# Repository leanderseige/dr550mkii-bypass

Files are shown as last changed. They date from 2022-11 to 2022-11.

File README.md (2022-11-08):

# Fixing Dr.Rhythm DR-550 MKII 

This is the documentation of how I fixed my DR-550 MKII. This is not a tutorial and this is not a recommendation. **WARNING! Trying to fix your machine this way may lead to irreparable and ultimate damage. It definetly would modify it irreversible. Please note that opening and modifying your device is on YOUR OWN RISK AND RESPONSIBILITY.**  And by the way, your machine may have another defect than mine.

I have one of those broken BOSS DR-550 MKII with extremely low and noisy signal on the outputs. And I couldn't find any documentation on how to fix it. But it was a huge help to find the "service notes" manual online, including the circuit diagram of the entire machine here: https://www.synthxl.com/boss-dr-550-mkii/ (PDF: https://www.synthxl.com/wp-content/uploads/2020/03/Boss-DR-550-MKII-Service-Notes.pdf)

I could hear the signal very low on the left headphone which gave me hope that the entire digital part of the machine would be ok and that just the analog output amplifiers would be the problem. I was not able to find any visual indications of faulty components. Capacitors and everything else looked good. So the next idea was to find the output pins of the digital-analog converter (DAC) to see if there was actually a proper analog signal produced.

With the help of the service manual I was able to identify IC103 as the DAC chip and PINs 6 and 11 to be the primary analog output pins. So I built the following simple stereo amplifier in order to connect the machine to other audio devices, in my case my audio mixer. This solution is not really a fix, it is a bypass, so to say.

Warning! Your device may suffer from a different problem and imitating the following steps might not solve your problem. Opening and/or modifying your device is on your own risk and it is very likely that you will loose any warranty. Some of the following steps modify the device irreversibly. This is a documentation of what I did. This is not a tutorial, not even a recommendation.

## Amplifier

I decided to use a very simple one-transistor amplifier just to see if my plan would work at all. I experimented with different values for the components and this was the first attempt delivering a usable signal to my audio mixer. I am sure this can be done better. Feel free to make suggestions for a better amp. The stereo panorama seemed not to be right in the middle, maybe I should have searched components for both channels which match each other as good as possible. I intend using the left (mono) channel in most cases anyway so this is no big thing at all. Turning the pan knob a little doesn't hurt either.

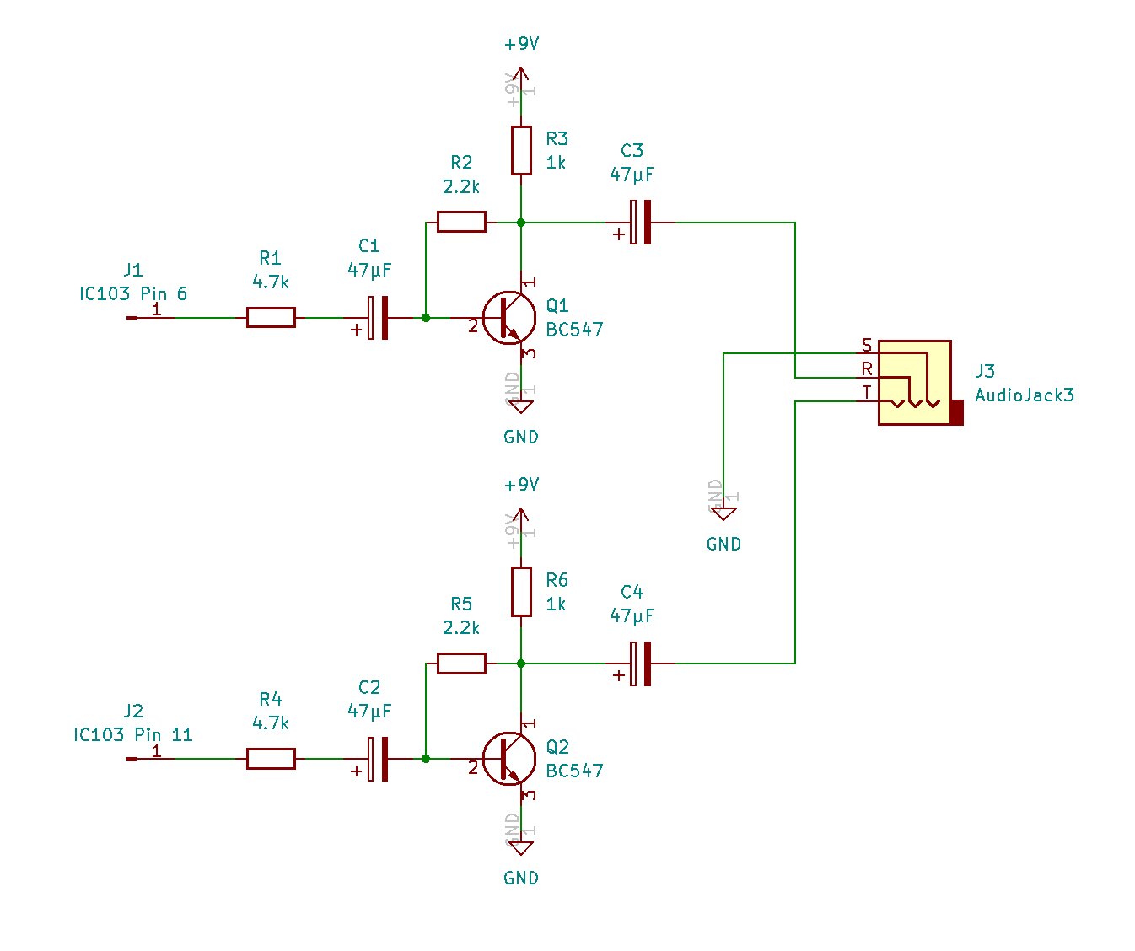
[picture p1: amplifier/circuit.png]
Stereo Amplifier


## Modifications

I attached the amplifier to Pins 11 and 6 of the DAC IC103 which provide the left (11) and right (6) analog audio channels.

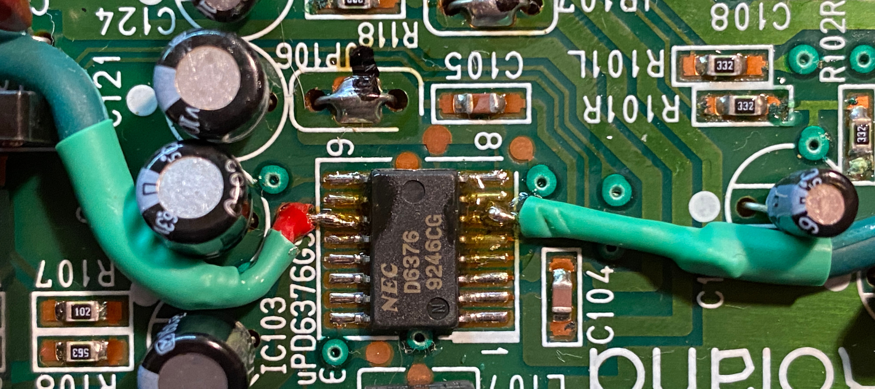
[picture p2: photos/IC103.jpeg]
ataching to DAC


Analyzing the original circuit diagram of the DR-550MKII -- I identified the capacitor C101 as the perfect spot to attach wires for stealing +9V in order to power the amplifier. 

(Left: top side, Right: bottom side with wires attached)

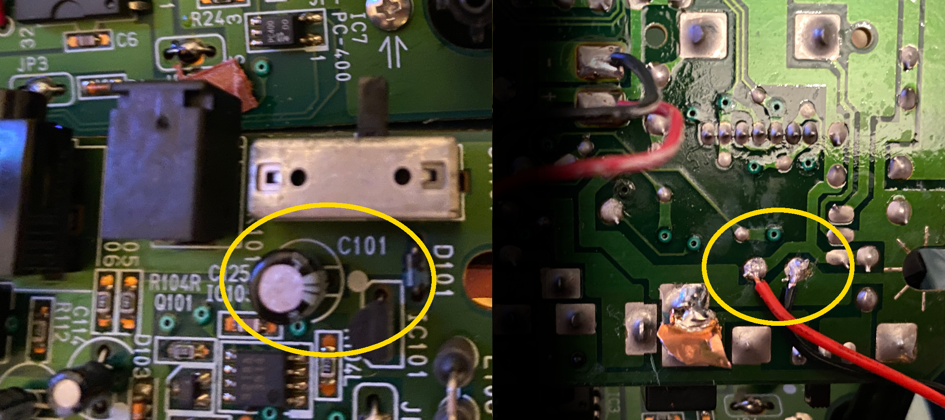
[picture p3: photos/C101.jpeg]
powering the DAC


## Damaging

In order to get the output out of the case I cut the axis of the original volume potentiometer. I also cut open the foil several times.

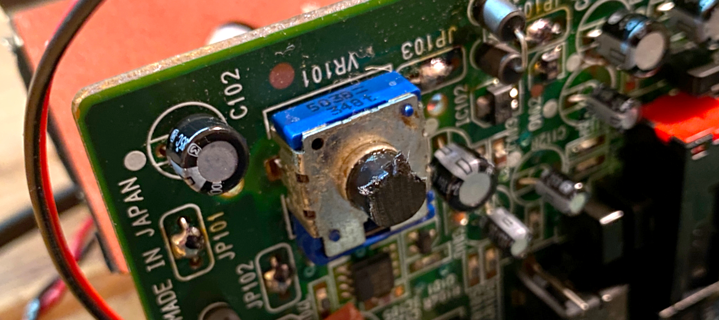
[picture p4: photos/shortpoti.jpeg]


## Putting it all together

Eventually I removed the battery compartment completely in order to use the space for the amplifier. Attention: the outer layer of the foil conducts electricity! I had to isolate the amplifier using bubble wrap.

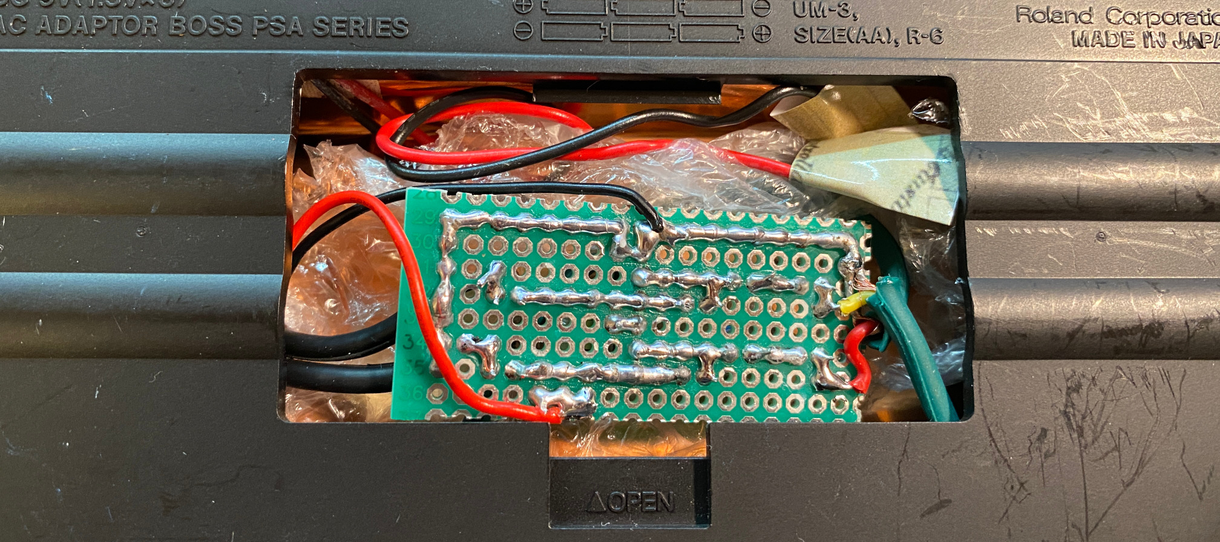
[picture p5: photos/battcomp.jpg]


I also removed the now uselss volume knob. Instead I designed a case for a 3.5mm jack fitting perfectly where the former volume knob was.

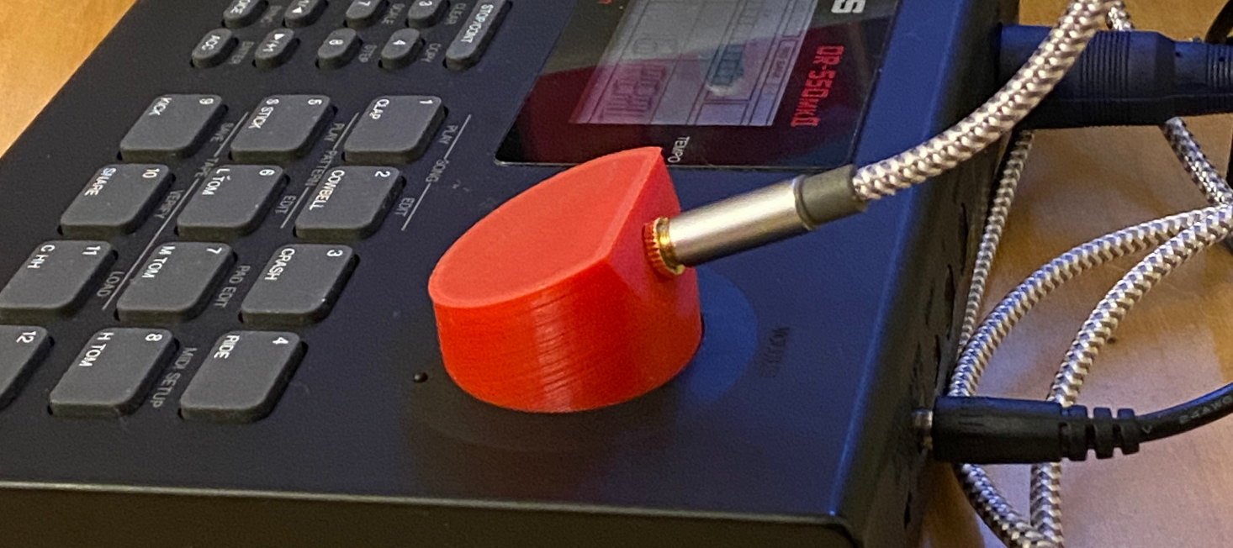
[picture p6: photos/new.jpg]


The 3D model is pre-rotated for optimal printing.

**WARNING!** Any of the above steps can ruin your device! Opening or modifying your device is on your own risk!

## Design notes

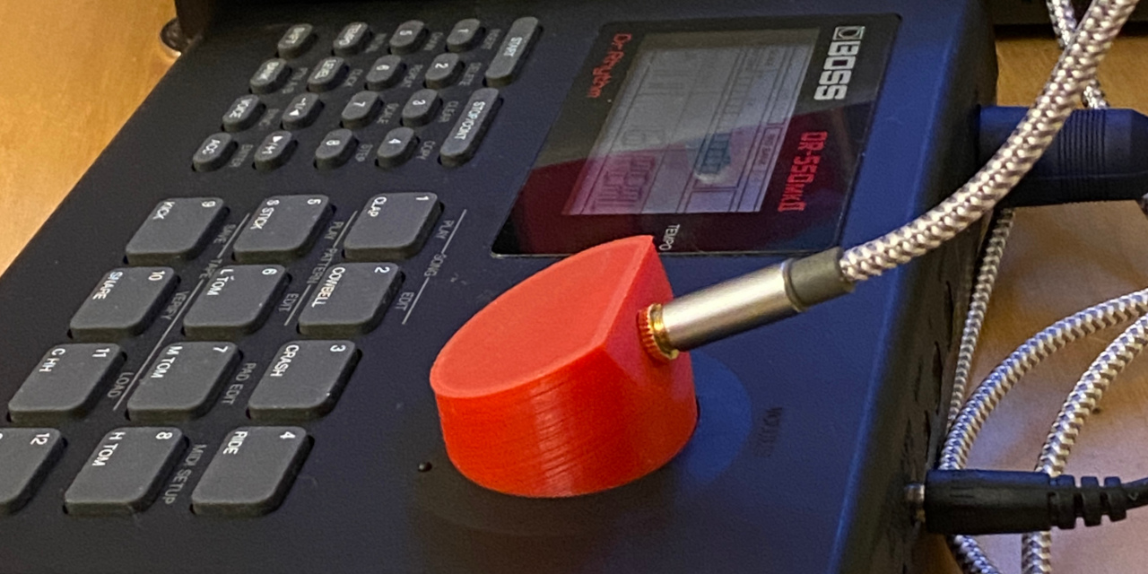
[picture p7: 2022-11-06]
photos/social.jpg

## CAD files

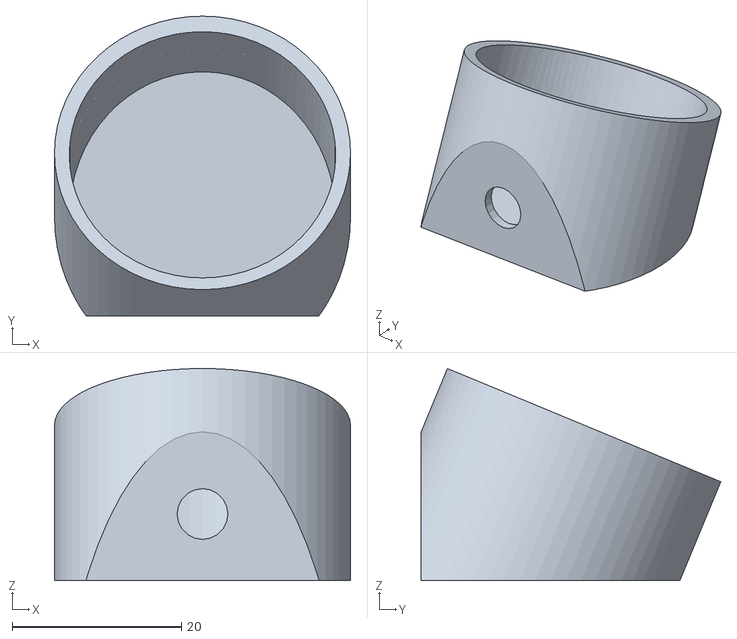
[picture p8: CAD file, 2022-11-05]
3dmodel/outputcase.stl
35.0 x 35.4 x 25.1
